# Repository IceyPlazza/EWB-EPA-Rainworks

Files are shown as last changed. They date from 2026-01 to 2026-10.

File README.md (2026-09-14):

<h1> For Visitors / New Members: </h1>

- Please browse through the key presentations folder to familiarize yourself with the general goal of Rainworks!
- Having some background in Java or C++ would assist you immensely if you're joining the CS Team.
- main branch is our last working version, main_revamp_WIP branch is our experimental/work-in-progress branch
- Please browse through the .ino files in both our main branch and WIP branch; documentation should help make understanding the code intuitive

<h1>For Returning Members:</h1>

- Glad to have you back! New tasks will be assigned to you every meeting depending on number of members in attendance and project progress
- Instructions to debug the Arduino can be found in arduino_debug.md
- Thingspeak overview for data collection can be found in thingspeak_data_collection.md
- Additional helpful resources in resources.md

<h1> NEW FOR 2026-2027 </h1>

All teams will now be using GitHub for version control!

<h1>Contact me if you have any questions! (Or send me code):</h1>

- iven.chen@vanderbilt.edu

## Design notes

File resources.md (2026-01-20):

<h1> Components: </h1>

- Data Collection: https://thingspeak.com/channels/2026236 

- Arduino Board: https://www.sparkfun.com/products/13231 

Please familiarize yourself with the basic information in the two links.
Breadboards and other components can be used to prototype our design and test the code 

<h1> HELPFUL PROGRAMMING RESOURCES </h1>

- Understanding the ESP.deepSleep() command: https://randomnerdtutorials.com/esp8266-deep-sleep-with-arduino-ide/ 

- The Arduino Guide to Low Power Design: https://docs.arduino.cc/learn/electronics/low-power/#power-source-guide--self-discharge-rates 

- SparkFun ESP8266 Library (Takes a bit of patience to read): https://github.com/sparkfun/SparkFun_ESP8266_AT_Arduino_Library 

- ThingSpeak Library (Very well documented, read the code comments): https://github.com/mathworks/thingspeak-arduino/blob/master/src/ThingSpeak.h 

- Estimate Power Consumption: https://docs.arduino.cc/learn/electronics/power-consumption/#power-consumption-example 

- SD Library: https://docs.arduino.cc/libraries/sd/

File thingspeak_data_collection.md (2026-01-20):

<h1>We have decided to use Thingspeak</h1> 

- https://thingspeak.com/

# Repo containing examples with ESP8266 sending data to a Thingspeak channel:

- https://github.com/nothans/thingspeak-esp-examples 

- https://github.com/mathworks/thingspeak-arduino 

<h1>DATA Sensors: </h1>

- pH  

- Rainwater/Water flow 

- Turbidity 

- Soil Moisture 

- Conductivity 

<h1> Plan: </h1>

- Use Thingspeak - thingspeak-esp-examples/A0_to_ThingSpeak.ino at master  

- What a message is - https://thingspeak.mathworks.com/pages/license_faq  

- https://www.mathworks.com/help/thingspeak/bulkwritejsondata.html 

- https://www.mathworks.com/matlabcentral/answers/879518-how-can-i-write-multiple-fields-all-at-once-using-thingspeak-library

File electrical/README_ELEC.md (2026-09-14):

# Electrical Subteam for Stormwater Runoff Device

This is the GitHub to maintain PCB (Printed Circuit Board) files for the EPA Rainworks Project. This 
board is relatively simple:
- 5 sensors that all connect with simply a VDD, GND, and INPUT connection
- ESP 8266 ThingDev MCU as the microcontroller (plug and place with header pins, will not be using the raw ICs for this
- ADC (Analog to Digital Converter) to convert analog sensor readings to a digital format for MCU communication and data processing.
- SD Card reader to store data in in case data storage over WiFi fails underground.
- Passives for the SD card reader (since we do NOT plan on using a module)

This circuit was originally designed in EasyEDA, but we are transitioning to design in KiCad, which all 
future files should be in.

Questions? Contact
Vivian Zeru (vivian.zeru@vanderbilt.edu) (ECE, Class of 2027)

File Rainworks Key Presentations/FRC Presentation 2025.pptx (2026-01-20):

## Engineers Without Borders Rainworks Project

Electronics box

GOAL: Improve stormwater management on flood prone areas by collecting groundwater data which will help formulate future bio-sustainability proposals and projects on the Vanderbilt Campus

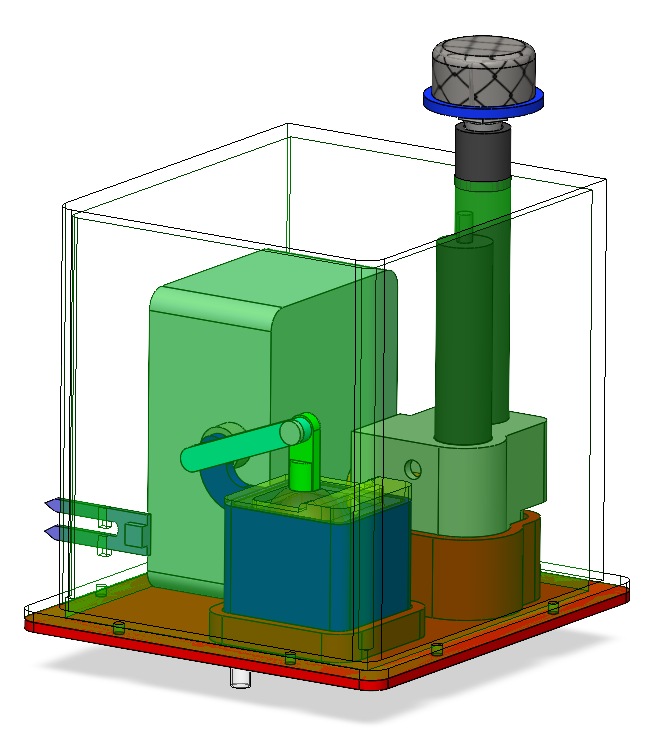
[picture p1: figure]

Water inlet

- 8.8” x 8.2” x 8.2” exterior dimensions
- 3D printed and made water resistant with Silicone loctite
- Internal battery powered sensor system
- Base of mesh cap is placed flush with the ground to allow groundwater flow into the inlet

Water outlet

## Locations

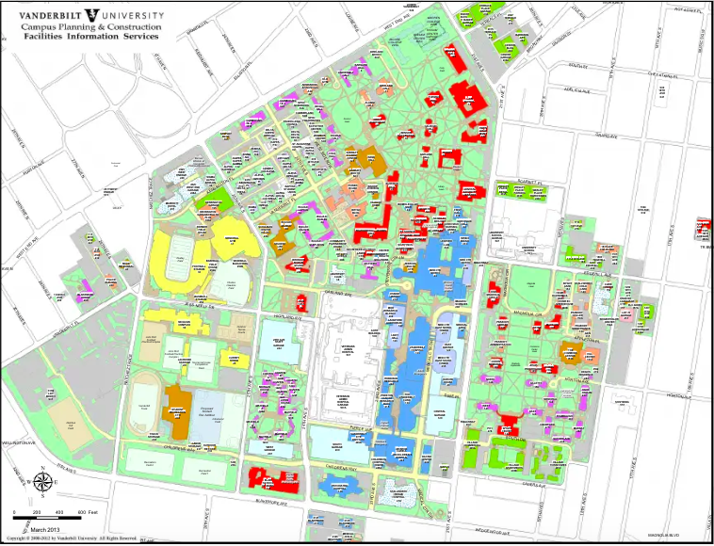
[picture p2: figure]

1

At the moment only one box will be placed in the ground.
Possible locations:
1. Outside admissions building
2. Bottom of Peabody Esplanade
3. Highland Chaffin Area
Digging will only take up a maximum of 1ftx1ft spaces within the grass, which could be supervised by maintenance.

2

3

## Timeline

- Box installed on April 20, 2025
- Box removed by May 6, 2025
- One sign that describes the project and requests people to avoid the area
- Sign will be on an A-frame placed next to the box
- There will be weekly routine check ups and maintenance by EWB members to ensure prototype functionality

## Signage

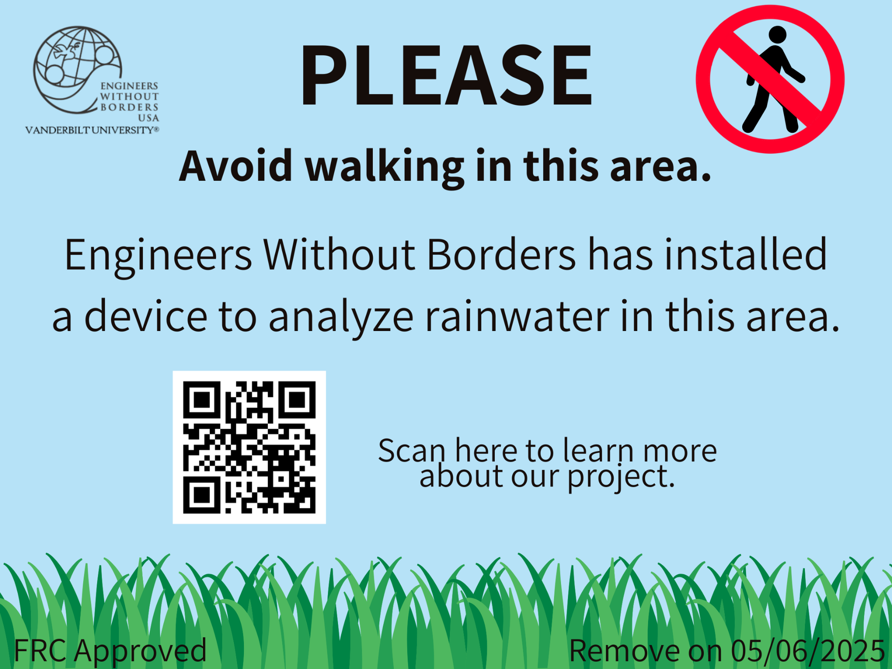
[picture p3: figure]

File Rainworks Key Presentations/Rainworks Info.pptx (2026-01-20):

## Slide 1

Welcome to Rainworks

Engineers Without Borders

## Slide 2

Rainworks Origin

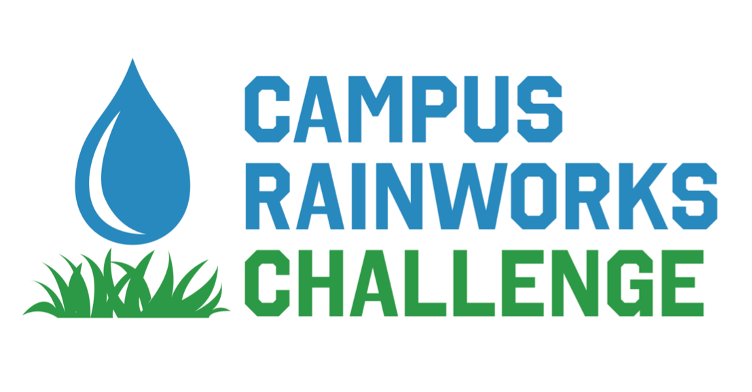
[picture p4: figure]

- Group started in Fall 2020
- Competition hosted by Environmental Protection Agency (EPA)
- Green infrastructure design challenge on college campuses
- Original idea was green roof on SLC

## Current Design

- A 3D printed, waterproof box has been buried in the ground on Alumni Lawn
- There is an inlet and outlet that allows rainwater to flow through the two reservoirs in the box connected by tubing
- Housed inside the box are 5 different sensors:
  - Turbidity
  - Flow
  - pH
  - Soil moisture
  - Conductivity
- The data gathered by the sensors can be used to determine whether green infrastructure is necessary in a certain area and what types of plants to put in a rain garden

## Mechanical

- 3D-printed box that holds all sensors and the electronics
- Two reservoirs
  - One holds the pH sensor, conductivity, and turbidity sensors
  - Other holds the flow sensor
- Flow sensor contains a potentiometer with a Pythagoras cup
- Water enters the box through the mesh on the top
- Water flows through both reservoirs before leaving out the bottom


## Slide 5

Electrical

- Microcontroller reads value of each sensor periodically
- Analog to Digital Converter (ADC) to convert sensor signals into signals that can be read by computer
- Batteries power the microcontroller

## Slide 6

Computer Science/User Interface

- Arduino code allows microcontroller to send data to Thingspeak
- One channel that all the data go to
- Each sensor has its own field
- Data is in real-time (sometimes up to 2 minutes to update)

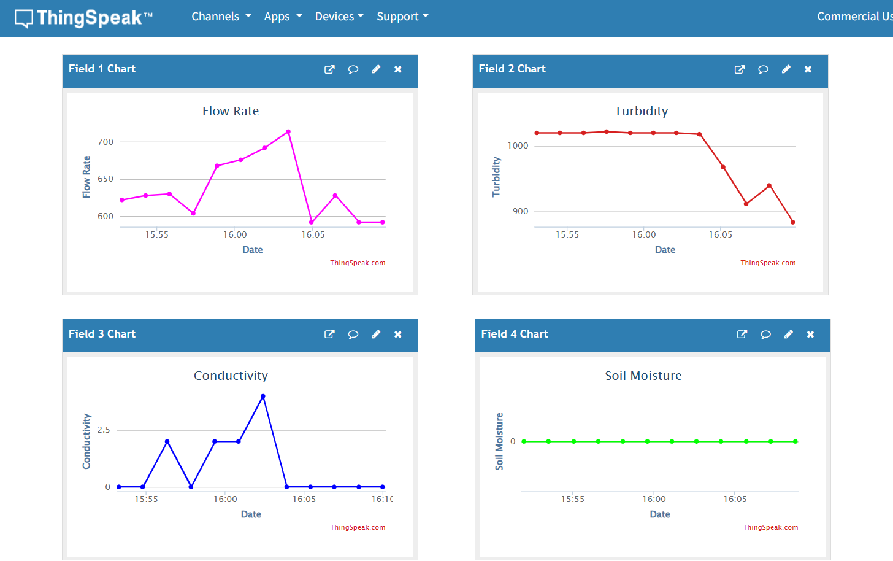
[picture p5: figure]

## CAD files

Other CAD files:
mechanical/Fall 2026.f3d

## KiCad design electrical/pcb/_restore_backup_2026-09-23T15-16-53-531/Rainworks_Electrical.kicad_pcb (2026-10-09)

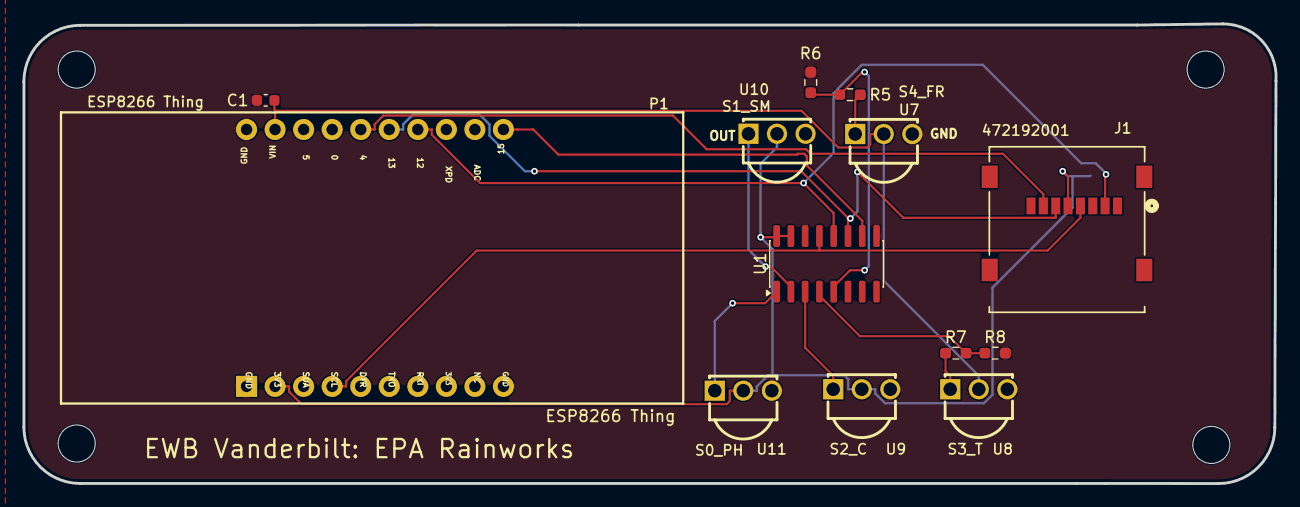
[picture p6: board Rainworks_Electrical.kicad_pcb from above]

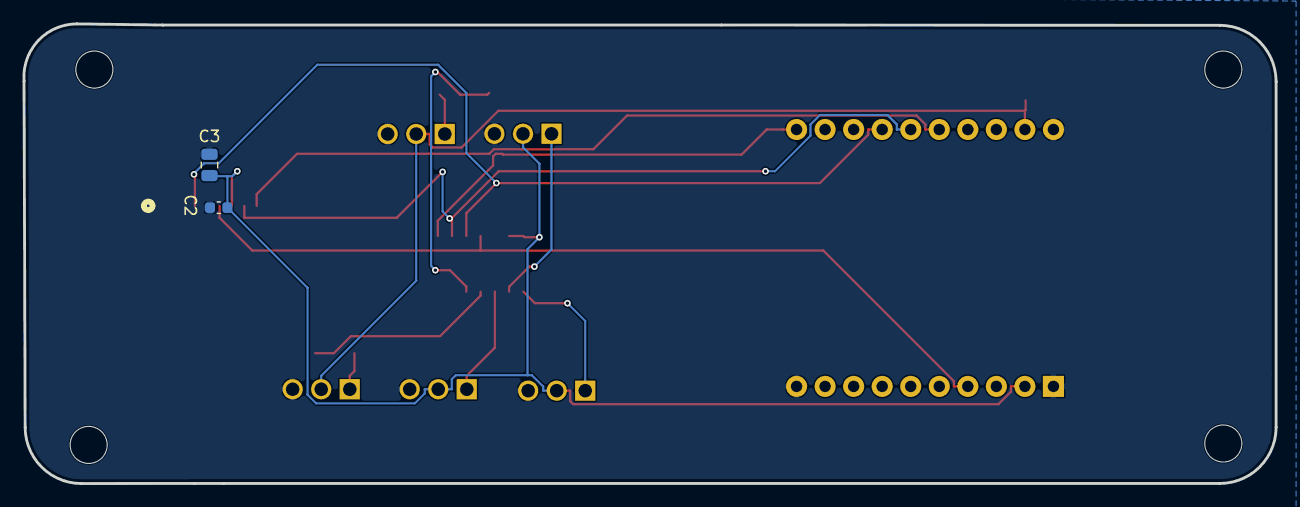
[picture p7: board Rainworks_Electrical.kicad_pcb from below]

Board: 2 copper layers, 111.4 x 40.9 mm, 19 parts (2 on the bottom side), 15 nets.

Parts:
C1: 100nF; C_0603_1608Metric
C2: 100 nF; C_0603_1608Metric
C3: 10 uF; C_0805_2012Metric
Hole_gge5569: Hole_gge5569
Hole_gge5584: Hole_gge5584
Hole_gge5599: Hole_gge5599
Hole_gge5614: Hole_gge5614
J1: 472192001; CONN_47219-2001_MOL
P1: ESP8266 Thing; ESP8266 THING
R5, R7: 15k; R_0603_1608Metric_Pad0.98x0.95mm_HandSolder
R6, R8: 10k; R_0603_1608Metric_Pad0.98x0.95mm_HandSolder
U1: MCP3008; SOIC-16_3.9x9.9mm_P1.27mm
U7: S4_FR; SENSOR-TH_TSOP32238
U8: S3_T; SENSOR-TH_TSOP32238
U9: S2_C; SENSOR-TH_TSOP32238
U10: S1_SM; SENSOR-TH_TSOP32238
U11: S0_PH; SENSOR-TH_TSOP32238

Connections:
/3V3_VDD: C2.1, C3.1, J1.4 (5), P1.12 (3V3), U1.15 (VREF), U1.16 (VDD), U9.2 (VDD), U10.2 (VDD), U11.2 (VDD)
/CH0_ADC: U1.1 (CH0), U11.1 (OUT)
/CH1_ADC: U1.2 (CH1), U10.1 (OUT)
/CH2_ADC: U1.3 (CH2), U9.1 (OUT)
/CH3_ADC: R7.2, R8.1, U1.4 (CH3)
/CH4_ADC: R5.2, R6.1, U1.5 (CH4)
/S3_T_VOUT: R7.1, U8.1 (OUT)
/S4_FR_VOUT: R5.1, U7.1 (OUT)
/SD_CS_SPI: J1.2 (7), P1.5 (4)
/SD_MISO_SPI: J1.7 (2), P1.7 (12), U1.12 (DOUT)
/SD_MOSI_SPI: J1.3 (6), P1.6 (13), U1.11 (DIN)
/SD_SCLK_SPI: J1.5 (4), P1.14 (SCL), U1.13 (CLK)
/VIN_5V0_MCU: C1.1, P1.2 (VIN), U7.2 (VDD), U8.2 (VDD)
GND: C1.2, C2.2, C3.2, J1.6 (3), P1.1 (GND), P1.11 (GND), P1.20 (GND), R6.2, R8.2, U1.9 (DGND), U1.14 (AGND), U7.3 (GND), U8.3 (GND), U9.3 (GND), U10.3 (GND), U11.3 (GND)
unnamed: P1.10 (15), U1.10 (SHDN!CS)

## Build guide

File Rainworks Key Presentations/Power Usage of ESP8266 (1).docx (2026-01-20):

10/27/2024

Use this document to estimate power consumption!

Overview

- Currently, microcontroller is powered by 3 AA batteries
  - This is a total of 4.5V
- The microcontroller needs 3.3V to operate
  - The ESP8266 Thing Dev has a built-in voltage regulator, so it can be fed up to 6V and still operate correctly
- The 1.5V batteries will begin to drop in voltage quickly
  - How quickly depends on how much current the microcontroller is drawing
- Standard capacity of AA batteries is 2000mAh (regardless of how many are in series)
  - Average current draw of Thing Dev is 80mA
  - This results in a theoretical lifetime of 25 hours
  - The true hours of reliable operation are lower because the voltage supplied to the microcontroller would drop below 3.3V before that
- Transmitting data over Wi-Fi will require more current than 80mA (probably about 150mA)
- Deep sleep should be used to prolong the battery life
  - Microcontroller only uses 20µA while in deep sleep
  - Needs to reconnect to WiFi when waking up from deep sleep
- Say deep sleep is used and Thing Dev is brought out of sleep every 15 seconds
  - 4,320 wake ups each day (20 seconds total between sleeping and active)
  - Say it takes 5 seconds to connect to Wifi, read all sensors and transmit data
  - 4,320 ×5=21,600seconds = 360 minutes=6 hours each day
- NEED TO SLEEP LONGER THAN 15 SECONDS BETWEEN MEASUREMENTS

Using Deep Sleep

- ESP.deepSleep(time)
  - Time specified in MICROSECONDS
- When microcontroller comes out of deep sleep it runs the setup block
  - There should be no need for the loop block
- Reset pin needs to be connected to GPIO 16
  - CONNECT RST PIN TO GPIO 16 ONLY AFTER UPLOADING THE CODE (https://randomnerdtutorials.com/esp8266-deep-sleep-with-arduino-ide/)
  - ESP 8266 Thing Dev has a built-in SLEEP-EN jumper that achieves this
  - Solder 2-pin male headers and then just slide the 2-pin jumper on and off

Vin vs. 5V pins

- In the breadboard design, all of the sensors and the ADC are powered by Vin
- Vin is directly connected to whatever is supplying the board with power
- 2400 mAh Batteries
- Average current draw of Thing Dev is 80mA
- Roughly 30 hours of battery lifetime
- Assume 15 seconds each time to read from sensors, connect to wifi, initialize SD, and other operations. This means 720 wake ups a day.
- So roughly 720 wakeups * 15 seconds in operation = 10800 sec = 180 mins = 3 hours a day. 30 hours total lifetime / 3 hour a day = 10 days!

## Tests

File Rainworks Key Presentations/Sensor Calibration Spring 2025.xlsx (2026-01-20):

Sensor | Voltage Output Range | Measuring range | Unit of measurement | Solution needed
Conductivity | 0 to 2.3V | 0-1000ppm | ppm | table salt, distilled water | for conductivity,a year ago we calculated the molarity of various mg/L samples (see this link) (https://docs.google.com/document/d/1N2nI_3WXOpv-BpY2zDJEKfTFiOwmpDde2TpnqwlLabo/edit?usp=sharing)
pH Sensor | -414 to 414 mV | 0-14 pH | pH | Solutions of known pH
Turbidity | 0 to 4.5 V | 0-3000 NTU | NTU | one milligram of Formazin per liter of water is considered to produce a turbidity of 1 Nephelometric Turbidity Unit (NTU)
Flow/Potentiometer | 0.25 to 4.75V |  | Ohms or m³/s | Water, Pythagoras cup, syringe
Soil Moisture | 0 to 4.2V | 0-950 | Volumetric Water Content (%) | Sample of soil, scale, oven, container of known volume, water | Use formula (volume of water)/(volume of soil)
 |  | (for potentiometer)

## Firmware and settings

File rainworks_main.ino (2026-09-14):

//Libraries to use
#include "ThingSpeak.h"
#include "SPI.h"
#include "SD.h"
#include <ESP8266WiFi.h>

//ThinkSpeak API
unsigned long myChannelNumber = 2637657;
const char * myWriteAPIKey = "08KCACI3TEVK7VSE";

//Wifi connection we expect to be using
char ssid[] = "vuDevices";   // your network SSID (name)
char pass[] = "Acorn1873";   // your network password
int keyIndex = 0;            // your network key index number (needed only for WEP)
const int ADC_CS_PIN = 15;   //Pin connected to CS/SHDN pin on MCP3008
WiFiClient  client;

//Create Object of SPI class (This is how we are reading from sensors)
SPIClass mySPI;
// Sets the speed of SPI data transmission (Hz), order of bits transmitted, and the mode which determines clock polarity and phase
SPISettings adcSettings(100000, MSBFIRST, SPI_MODE0);

//Extra needed variables. Uncomment variables when we swap implementations.
// bool isRaining = false; //Check if raining or not
// int rainingFast = 20; //Value if it's raining fast. Can figure out later
int deepSleepTime = 120e6; //Variable to determine how long to sleep for: 120e6 means 120 seconds or 2 mins. Should give battery life of 10 days
// int prevRainValue = 0; //Variable to store and check a prior raining value

void setup() {

  //Initial setup
  Serial.begin(115200);
  pinMode(ADC_CS_PIN, OUTPUT);
  mySPI.begin(); 

  //Series of actions to take before we deepSleep.
  Serial.println("\nStarting up...");
  WiFi.mode(WIFI_STA);
  bool connected = connectWifi();
  writeMain(connected);

  //Let's wait an extra tenth of a second just in case there's any delays we might have to deal with
  Serial.println("\nEntering Deep Sleep for " + String(deepSleepTime/1000000) + " seconds.");
  ESP.deepSleep(deepSleepTime);
}

void loop() {
  //We supposedly won't need loop if using deepSleep
}

/*
////////////////////////////////////////////////
  Please keep all helper methods below this line
///////////////////////////////////////////////
*/

/**
  readFromADC -- function to help read data from each respective sensor connected to the respective channels
  @param channel - the channel to which the sensor should be attached
  @return - the reading from the sensor
*/
uint16_t readFromADC(uint8_t channel) {
  mySPI.beginTransaction(adcSettings);
  
    // MCP3008 command format: Start bit (1), Single-ended mode (1), Channel (3 bits)
    uint16_t command = 0xc000 | (channel << 11);

    // Select the MCP3008 by pulling CS low
    digitalWrite(ADC_CS_PIN, LOW);

    // Send the command
    uint16_t result = mySPI.transfer16(command);

    // Deselect the MCP3008 by pulling CS high
    digitalWrite(ADC_CS_PIN, HIGH);
    
    mySPI.endTransaction();

    // Extract the 10-bit ADC value from the result
    uint16_t adcValue = (result<<1) & 0x03FF;

    return adcValue;
}

/**
  connectWifi -- function to establish a Wifi connection
  @return -- True if successfully connected to Wifi, false otherwise
*/
bool connectWifi(){

  //Having this here just for in case a different non-registered board was used.
  Serial.println();
  Serial.print("MAC: ");
  Serial.println(WiFi.macAddress());

  // Connect to WiFi
  if (WiFi.status() != WL_CONNECTED) {
    Serial.println("Establishing WiFi connection: ");

    //Attempt to connect to Wifi 4 times. If all 4 fails, we will enter extended deep sleep, since it is likely that Wifi is currently down.
    for (size_t i = 0; i < 4; i++){
      if (WiFi.status() != WL_CONNECTED){
        WiFi.begin(ssid, pass); // Connect to WPA/WPA2 network. Change this line if using open or WEP network
        Serial.print(".");
        delay(10000); //Was told it needs 5-10 sec to connect
      } else {
        Serial.println("\nConnected.");
        return true;
      }
    } 
  }
    Serial.println("Wifi unavailable.");
		return false;
}

/**
  readSensors -- helper method to read and store all sensor values into an array. 
  @param sensorValues -- A uint16_t array with 5 array slots (as we have 5 sensors) Data is moved into this array
*/
void readSensors(uint16_t* sensorValues){

  // Runs 5 times to set each of the 5 field values
  // ADC channels are zero based indexing
  for (size_t i = 0; i < 5; ++i) {

    // Measure Analog Input (A0)
    sensorValues[i] = readFromADC(i);
    delay(100);

    //Checks if it's pin 4 and sees if it's raining fast or not.
    // NOTE: RESTORE THIS ONCE WE MOVE BACK TO VARIABLE COLLECTION
    // if(i==4){
    //   if( (prevRainValue-sensorValues[i]) < rainingFast){
    //     isRaining = false;
    //     deepSleepTime = 3000e6;
    //   }
    //   else((prevRainValue-sensorValues[i]) > rainingFast){
    //     isRaining = true;
    //     deepSleepTime = 15e6;
    //   }
    //   prevRainValue = sensorValues[i]
    // }
  }
}

/**
  writeToThingSpeak -- function to send all data in an array to ThingSpeak
  @param dataArray -- A uint16_t array with 5 array slots (as we have 5 sensors)
  @return True if we successfully wrote, false otherwise
*/
bool writeToThingSpeak(uint16_t* dataArray){
  
  // Load ThingSpeak fields
  for (size_t i = 0; i < 5; ++i){
    ThingSpeak.setField(i+1, dataArray[i]); //ThingSpeak is 1-based indexing
  }

  //Write all 5 ADC values to Thingspeak at the same time
  int httpCode = ThingSpeak.writeFields(myChannelNumber, myWriteAPIKey);

  //HTTP Code 200 means success, anything else means there was an error of some sort.
  if (httpCode == 200) {
    Serial.println("\nWriting to Channel 1 Field:\n");
    for (size_t i = 0; i < 5; i++){
      Serial.print(i+1);
      Serial.print(" with value ");
      Serial.println(dataArray[i]);
    }

    return true;
  }
  else {
    Serial.println("\nProblem writing to Channel 1 Field ");
    Serial.println("HTTP error code " + String(httpCode));
    return false;
  }
}

/**
  writeToSD - Opens SD card and creates a file to write data in series of 2 bytes for 10 bytes total
  postcondition - a new file is created containing 10 bytes, as 5 sensors need 2 bytes each

  @param dataArray - an array of size 5 (because we have 5 sensors) holding the data to write
*/
void writeToSD(uint16_t dataArray[]){

   initializeSD();

  //Creating a file to write to
  //Logic to correctly identify different files and available filenames
  size_t fileNum = 0;
  while(SD.exists("data" + String(fileNum) + ".txt")){
    ++fileNum;
  }
  File myFile = SD.open("data" + String(fileNum) + ".txt", FILE_WRITE);

  //Write data to file in terms of bytes
  for (size_t i = 0; i < 5; i++){
	uint8_t split[2];
    splitBytes(dataArray[i], split);
    myFile.write(split, 2);
  }

  myFile.close(); //Must close file when we are done to save changes.
}

/**
  readAllFromSD - Opens SD card to read all files stored on the SD card.
  postcondition - files read are deleted upon completion. Prevents deletion if failed to read
*/

void readAllFromSD(){

  initializeSD();

  // Uses root dir to find files.
  File root = SD.open("/");

  if (!root){
    Serial.println("Failed to open root directory.");
    return;
  }

  File entry = root.openNextFile();

  if (!entry){
    Serial.println("No files on SD card.");
    return;
  }

  //While we have files to read...
  while(entry){

    if (!entry.isDirectory()){

      String fileName = entry.name();

      // Upload relevant files.
      if (fileName.startsWith("data") && fileName.endsWith(".txt")){
        Serial.println("Found file: " + fileName);

        uint16_t results[5];

        readFromSD(fileName, results);

        bool upload = writeToThingSpeak(results);

        if (upload){
          Serial.println("File uploaded. Deleting " + fileName);
          SD.remove(fileName);
          delay(15000);
        } else {
          Serial.println("Failed to upload file: " + fileName);
          entry.close();
          root.close();
          return;
        }
      }
    }

    entry.close();
    entry = root.openNextFile();
  }

  root.close();
  Serial.println("Processed all files on SD card.");
}

/**
  readFromSD - Opens SD card to read a file into in series of 2 bytes for 10 bytes total
  precondition - file to read only has 10 bytes, 5 sensors need 2 bytes each

  @param fileName - which file to read from
  @param dataArray - an array of size 5 (due to 5 sensors) holding the data we read. 
  We also return data using this same array
*/
void readFromSD(String fileName, uint16_t* dataArray){

  initializeSD();
  
  //Read one file at a time
  File myFile = SD.open(fileName, FILE_READ);

  for (int i = 0; i < 5; i++) {
    if (myFile.available()) {
      uint8_t bytes[2];
      bytes[0] = myFile.read();
      bytes[1] = myFile.read();

      dataArray[i] = combineBytes(bytes);
    }
  }

  myFile.close();
}

/**
  writeMain -- function to determine whether to write directly to ThingSpeak or to SD card
  @param connectedWifi - Boolean to check if we have wifi or not
  //TODO: ADD TO THIS; DONT HESITATE TO EDIT OR CHANGE LOGIC IF YOU DISCOVER SOMETHING BETTER
*/

void writeMain(bool connectedWifi){

  uint16_t sensorValues[5]; //Array to store all sensor readings

	initializeSD();
	
  //First, check if we have wifi.
  if (connectedWifi) {
		ThingSpeak.begin(client); 
		readAllFromSD(); 
    
		readSensors(sensorValues);
		bool success = writeToThingSpeak(sensorValues);

    // Just in case we didn't write properly
    if (!success){
      writeToSD(sensorValues);
    }

  } else { // Don't have wifi, so let's just read and write to SD.
		readSensors(sensorValues);
		writeToSD(sensorValues);
	}
}

/**
  initializeSD - a void helper method to initialize the SD card. Goes to deepSleep if failed to initialize.
*/
void initializeSD(){

  int success = SD.begin(4);

  if (success == 1){
    Serial.println("SD already initialized!");
    return;
  }

  Serial.println("Initializing SD Card...");

  for (size_t i = 1; i <= 5; i++){
    success = SD.begin(4); //TODO: Could take a parameter; need Electrical to say which pin SD module is connected
    Serial.println("Initializing attempt: " + String(i));
    if (success == 1){
      Serial.println("SD Card Initialized!");
      return;
    }

    delay(5000); //Was told it needs 5-10 sec to connect
  }

  Serial.println("Initialization failed!");
	Serial.println("\nEntering Deep Sleep for " + String(deepSleepTime / 1000000) + " seconds.");
  ESP.deepSleep(deepSleepTime);
	return;
    
}

/**
  splitBytes - a helper method that takes a uint16_t value and split it into two seperate bytes
  @param twoBytes - a uint16_t value
  @param *bytes - a pointer looking at an array of two uint8_t bytes
*/
void splitBytes(uint16_t twoBytes, uint8_t *bytes){
    memcpy(bytes, &twoBytes, 2);
}

/**
  combineBytes - a helper method that takes an array of 2 bytes and merge them together in a new data type.
  @param bytes - a uint8_t array of size 2
  @return - a uint16_t value that's the result of merging the bytes in our parameter
*/
uint16_t combineBytes(uint8_t bytes[]){
  uint16_t twoBytes;
  memcpy(&twoBytes, bytes, 2);
  return twoBytes;
}

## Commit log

2025-09-22 Add data collection documentation for Thingspeak
    Documented the use of Thingspeak for data collection with various sensors.
2025-09-23 Add instructions for uploading code and reading serial messages
    Added detailed steps for uploading code to the board and reading serial messages.
2025-11-05 Refactor rainworks sketch for better structure
    Refactored the rainworks sketch to improve structure and functionality. Added methods for reading and writing to SD card, handling WiFi connections, and managing sensor data.
2025-11-12 Moved back to fixed time interval data collection times.
    Updated deep sleep time and modified sensor reading logic.
2026-01-18 Add arduino_debug.md file
2026-01-18 Improve formatting in arduino_debug.md
    Updated formatting and headings in the Arduino debug documentation.
2026-01-18 Update README with Arduino and Thingspeak resources
    Added debugging and data collection instructions.
2026-02-25 Fix memcpy usage in splitBytes and combineBytes
    [rainworks_main.ino]
2026-02-25 Refactor sensor reading functions and usage
    Refactor readSensors and readFromSD functions to use pointers for sensor values. Update writeMain to directly use sensorValues array.
2026-09-13 Add electrical PCB files and .gitignore for editor/KiCad artifacts
    [Rainworks_Electrical.kicad_pcb, Rainworks_Electrical.kicad_sch]
2026-09-13 Add CAD file
    [Fall 2026.f3d]
2026-09-15 Adding SD card passives and preparing for autorouter outside of KiCad, includes placement and schematic ERC checks
    [Rainworks_Electrical.kicad_pcb, Rainworks_Electrical.kicad_sch]
2026-09-18 changes for routing with sd
    [Rainworks_Electrical.kicad_pcb, Rainworks_Electrical.kicad_sch, temp-freerouting.dsn]
2026-10-08 fixed drc errors
    [Rainworks_Electrical.kicad_pcb, Rainworks_Electrical.kicad_sch, temp-freerouting.dsn]
2026-10-08 add test points to PCB
    [Rainworks_Electrical-BoardOutLine.gbr, Rainworks_Electrical-BottomLayer.gbr, Rainworks_Electrical-BottomPasteMaskLayer.gbr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]
2026-10-09 extra changes for tp
    [Rainworks_Electrical.kicad_pcb, Rainworks_Electrical.kicad_sch]
